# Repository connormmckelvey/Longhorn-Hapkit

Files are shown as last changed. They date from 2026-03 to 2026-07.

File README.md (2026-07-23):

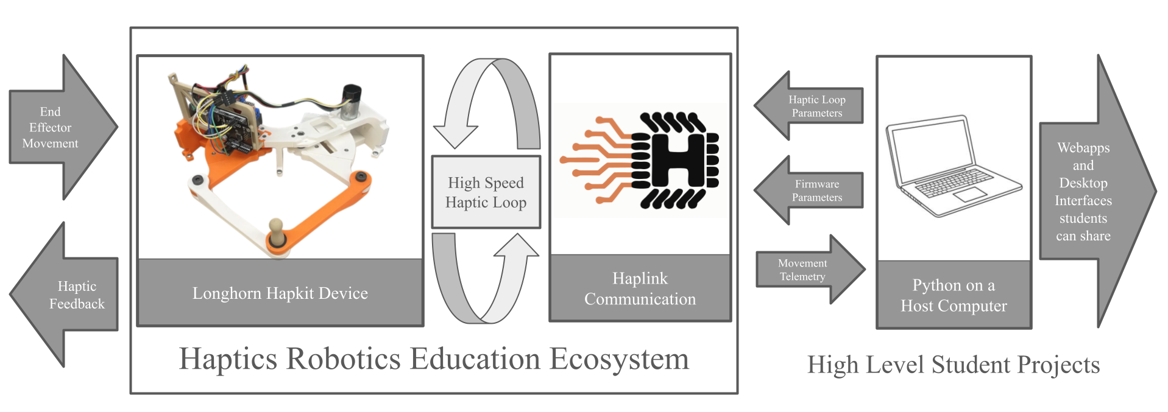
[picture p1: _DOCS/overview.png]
Overview


# The Longhorn Hapkit
### A Complete Haptic Robotics Education Ecosystem
---
###### Written by Ross Neuman and Connor McKelvey for the Human Enabled Robotics Lab at UT Austin under Professor Ann Fey.

> **A note to the reader:** The Longhorn Hapkit aims to provide a complete toolset to enable anyone to learn robotics through the interdisplinary and universal sense of touch. These low-cost devices enable students to learn mechanical design, electronics, and software engineering. Hopefully the provided documents supply an ample jumping off point for educators and ambitious students alike to look deeper into the field of robotics and create their very own projects and improvements to our ecosystem.

#### This Project Includes:
- 1 Degree of Freedom Haptic device design
    - A simple first device to build and learn what haptics is, use this to render your first artifical wall, dampener, or spring!
- 2 Degree of Freedom Haptic device design
    - Once you've mastered the 1-DOF enviroments, combine two of them into our 2-DOF design opening a world a possibilies. From teleoperation to pong games, use this device to make games or more complex simulations!
- Haplink implementation for device interfacing with Python

#### Repository Structure
```
DOCS/
    * supplemental material, diagrams, bill of materials
firmware/
    * files are numbered coresponding to /python scripts
    1DOF/
    2DOF/
    includes/ 
        * header files used by various scripts
python/
    1DOF/
    2DOF/
    tools/ 
        *helper scripts (e.g. to find connect ports)
README.md
platformio.ini *configuration file showing dependencies
```
#### Environment Setup
<table>
<!--
  <tr>
    <th colspan="2" align="center">Environment Setup</th>
  </tr>
-->
  <tr>
    <td width="50%"><b>Arduino IDE Setup</b></td>
    <td width="50%"><b>PlatformIO Setup</b></td>
  </tr>
  <tr>
    <td valign="top">
      1. Download and install the <b>Arduino IDE</b>.<br><br>
      2. Open the <b>Library Manager</b> from the left sidebar.<br><br>
      3. Search for <b>Haplink</b> by Connor McKelvey.<br><br>
      4. Select version <b>1.0.3</b> and click <b>Install</b>.<br><br>
      5. Select <b>Arduino Uno</b> as your board.<br><br>
      5. Copy the contents of <code>1_basic.cpp</code> into the main window and hit compile.<br><br>
      6. Write code!<br><br>
      Note: you will need to use another IDE to run future python scripts 
    </td>
    <td valign="top">
      1. Download and install <b>VS Code</b> with the <b>PlatformIO Extension</b>.<br><br>
      2. Open the <b>PlatformIO Home</b> and create a new project.<br><br>      
      3. Open the <b>PlatformIO Home</b> and click on <b>Libraries</b>.<br><br>
      4. Search for <b>Haplink</b> by Connor McKelvey.<br><br>
      5. Copy <code>1_basic.cpp</code> into the <code>src/</code> folder of the project<br><br>
      6. Run <code>PlatformIO:Upload</code> and watch the magic happen.<br><br>
      7. When you are ready to interface with Python, navigate to <a href="https://github.com/connormmckelvey/Haplink">github.com/connormmckelvey/Haplink</a> and follow the instructions for PlatformIO install.
    </td>
  </tr>
</table>

<div style="display: flex; justify-content: center;">
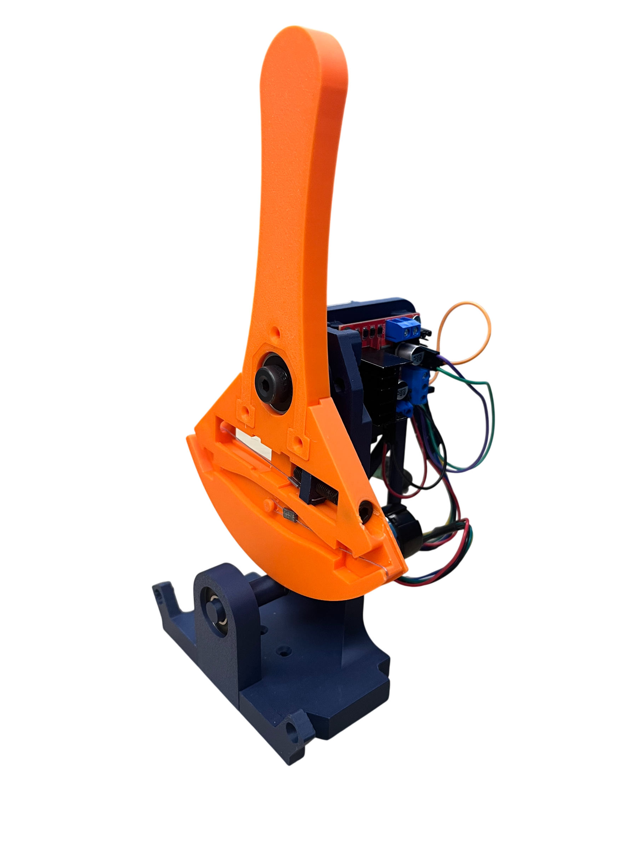
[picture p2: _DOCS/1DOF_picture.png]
1DOF
  
</div>

#### 1-DOF Longhorn Hapkit
The 1 Degree of Freedom design implements a single capstan drive to control the end-effector position. 

<div style="display: flex; justify-content: center;">
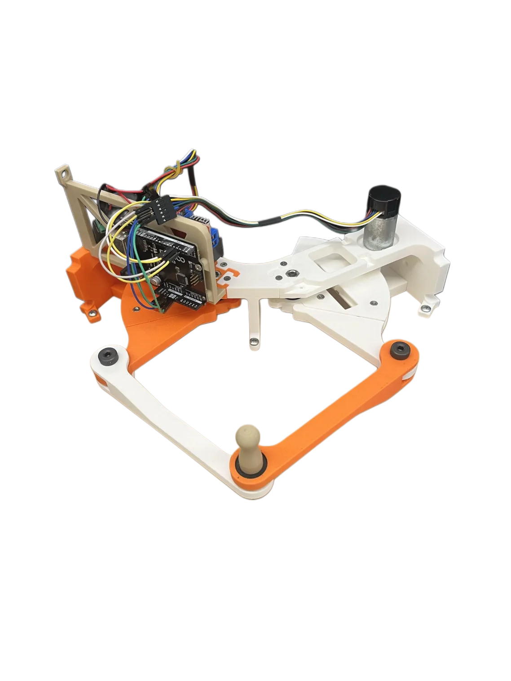
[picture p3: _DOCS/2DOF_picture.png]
2DOF
  
</div>

#### 2-DOF Longhorn Hapkit Expansion
blah blah

<div style="display: flex; justify-content: center;">
  HAPLINK
</div>

#### Python Interfacing with Haplink
blah blah

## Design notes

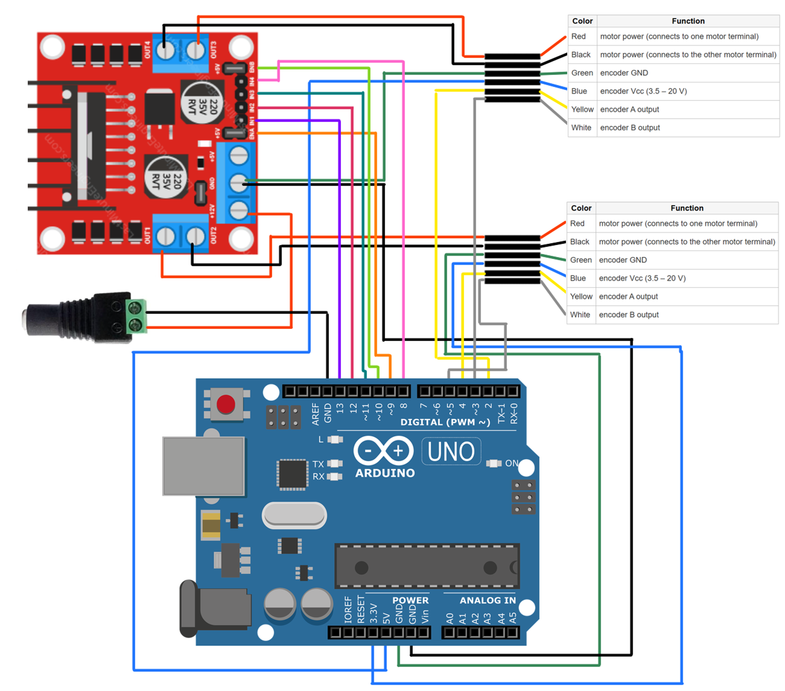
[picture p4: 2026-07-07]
_DOCS/2DOF_wire_diagram.png

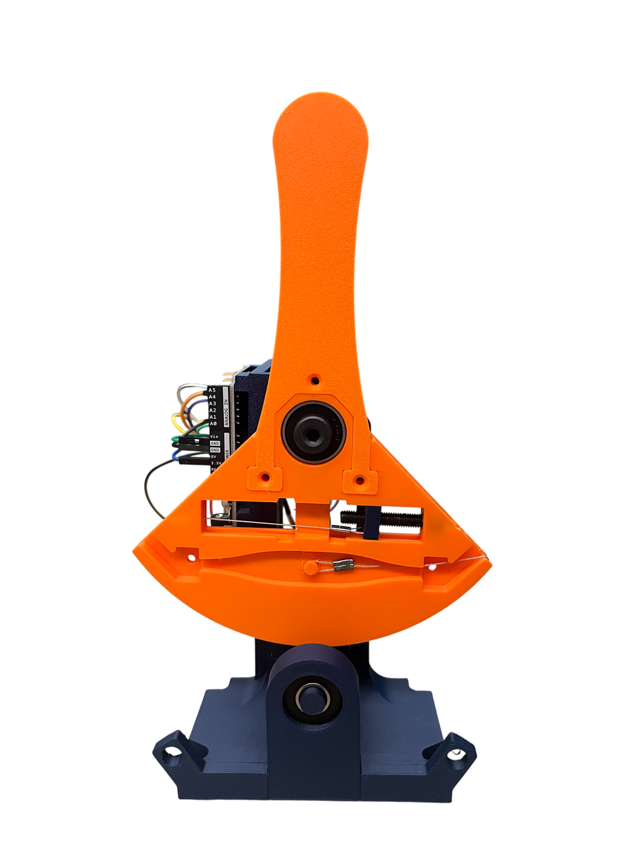
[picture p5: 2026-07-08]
_DOCS/1DOF_picture_front.png

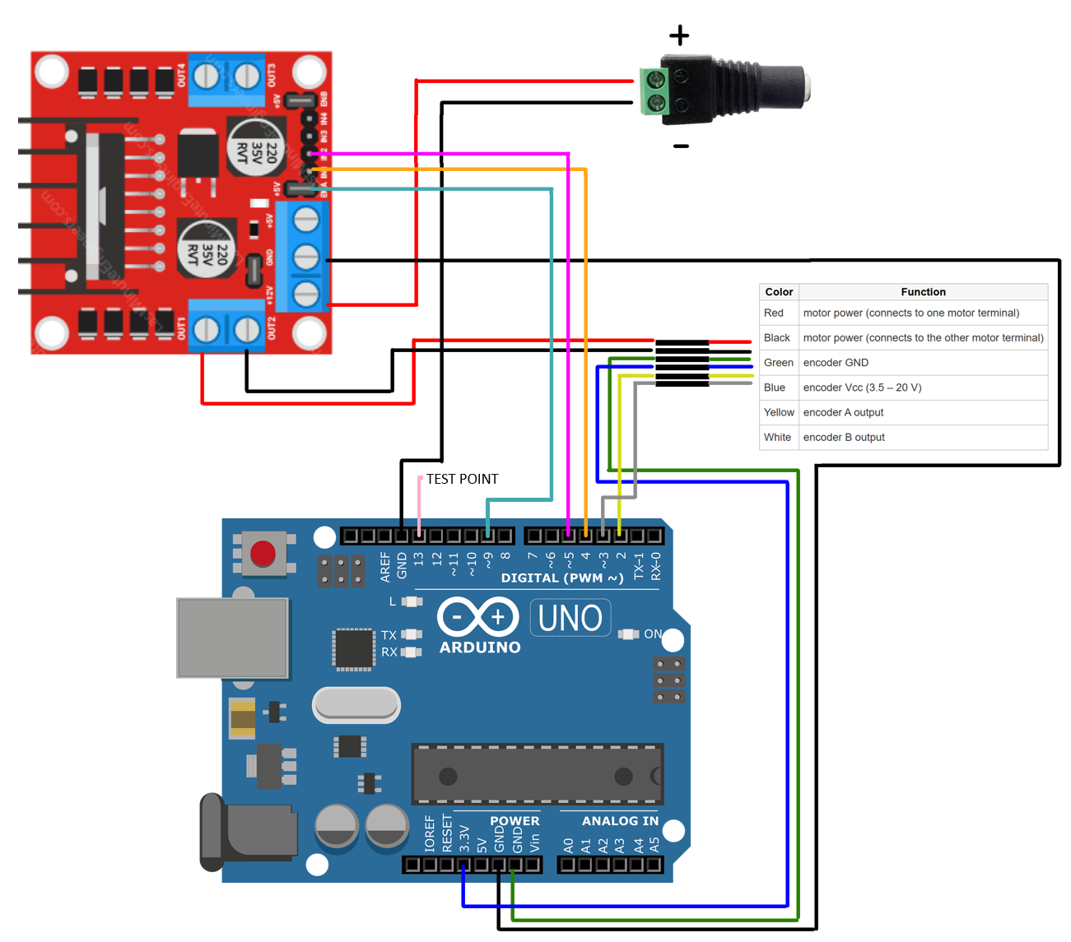
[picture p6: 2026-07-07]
_DOCS/1DOF_wire_diagram.png

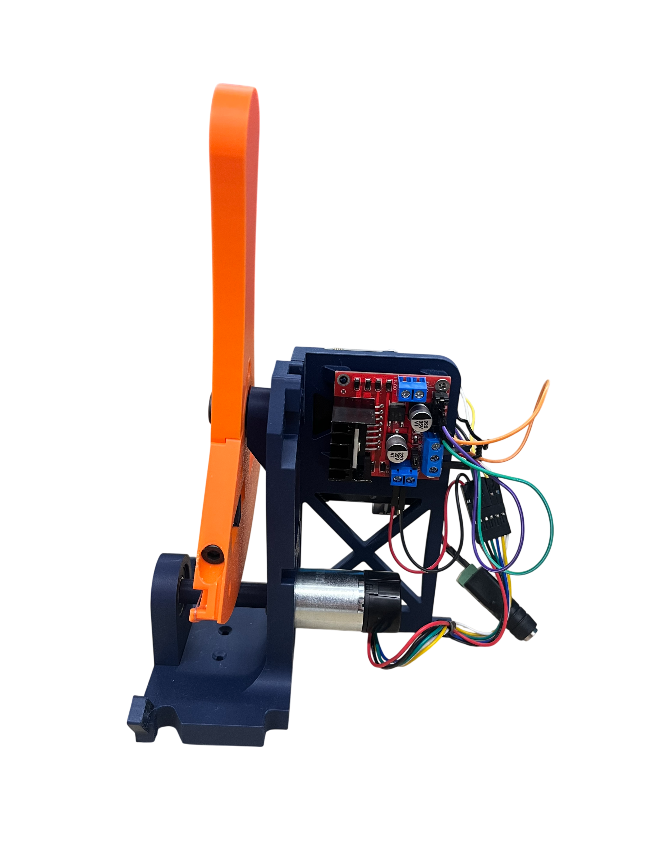
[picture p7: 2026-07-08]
_DOCS/1DOF_picture_side.png

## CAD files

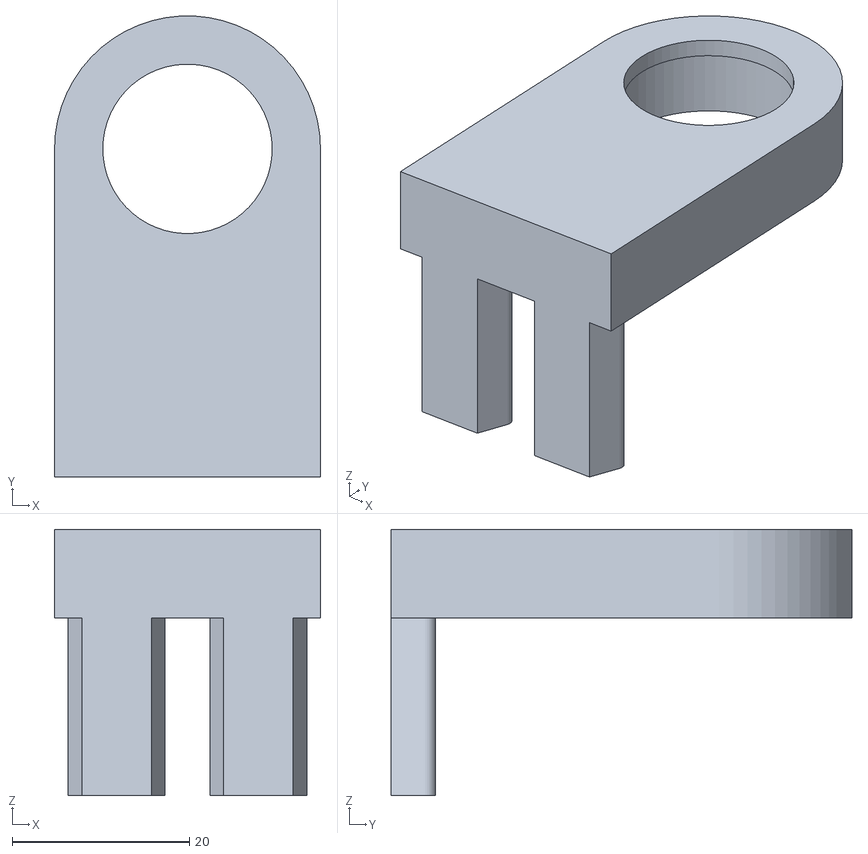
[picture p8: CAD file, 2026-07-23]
cad/1DOF/bearing_housing.stl
30.0 x 52.0 x 30.0

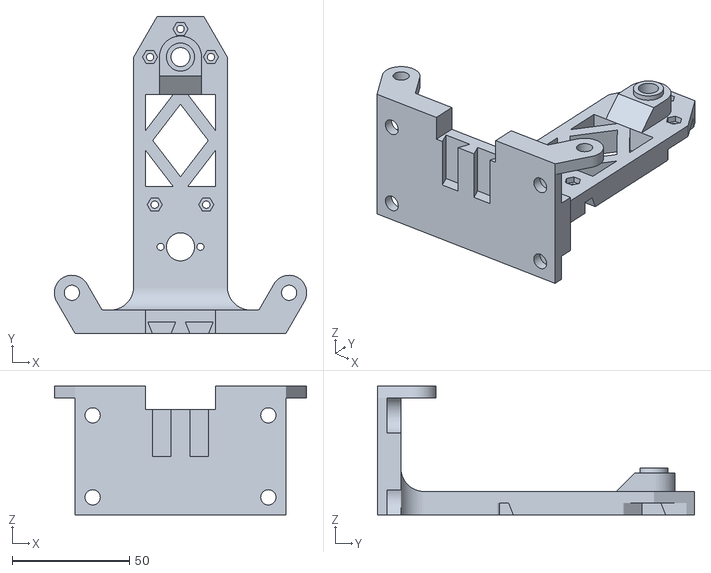
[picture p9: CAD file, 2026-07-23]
cad/1DOF/base.stl
107.7 x 135.3 x 55.0

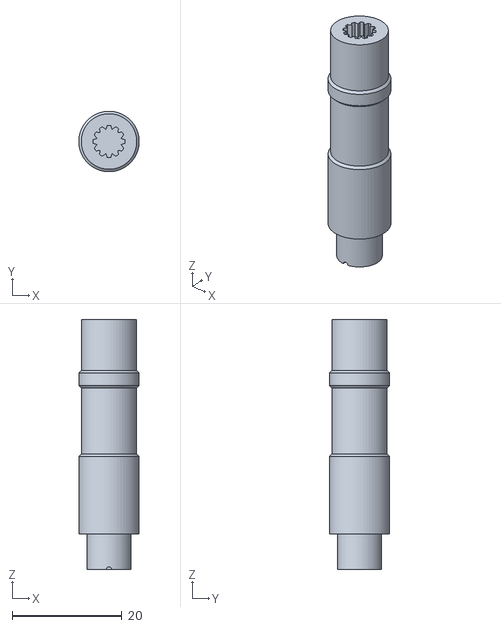
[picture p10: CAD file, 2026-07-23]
cad/1DOF/motor_shaft.stl
11.0 x 11.0 x 45.5

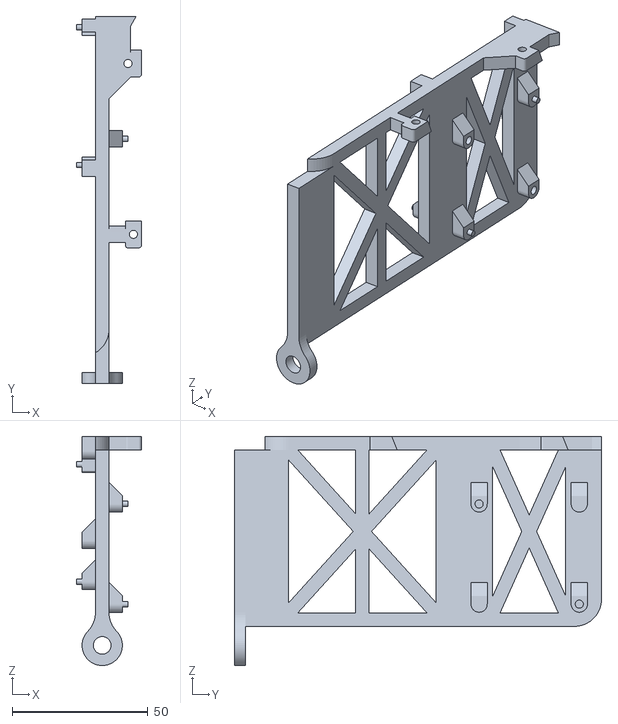
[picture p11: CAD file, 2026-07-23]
cad/1DOF/pcb_mount.stl
24.0 x 135.3 x 84.4

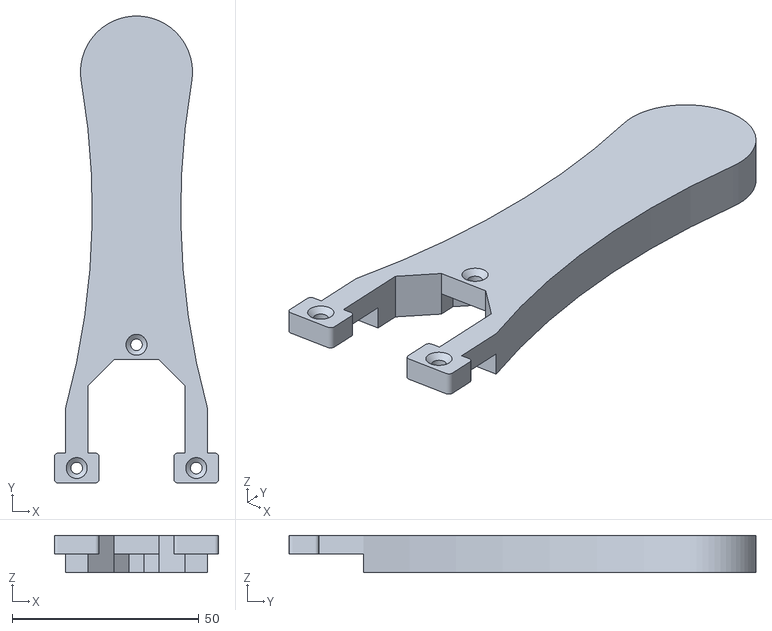
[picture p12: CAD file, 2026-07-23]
cad/1DOF/handle.stl
44.0 x 125.0 x 10.0

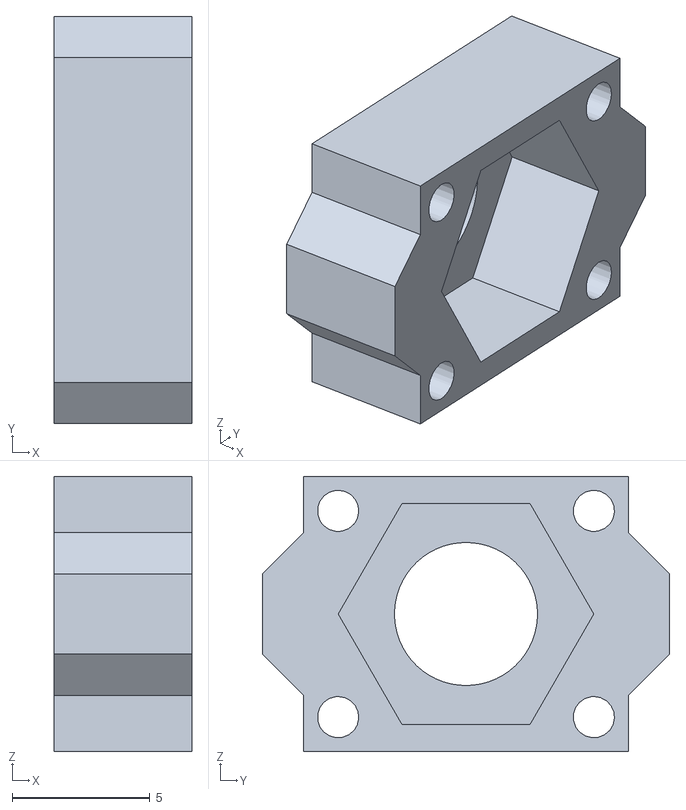
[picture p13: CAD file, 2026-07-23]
cad/1DOF/tensioner.stl
5.00 x 14.8 x 10.0

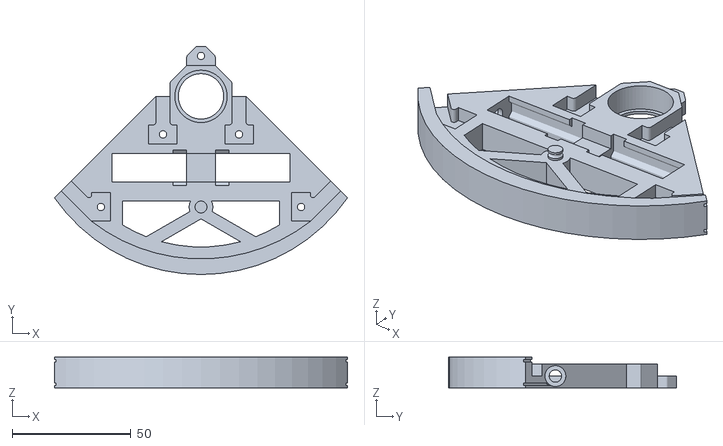
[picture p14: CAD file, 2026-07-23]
cad/1DOF/sector_pulley.stl
123.4 x 96.0 x 13.0

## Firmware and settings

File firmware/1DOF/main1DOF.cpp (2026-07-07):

//IF YOU USE THIS CODE, MAKE SURE THE PWMout WIRE IS MOVED TO PIN 9
//Write all serial messages in loop(), do not do serial communication in ISR

//Hapkit basic environments code + CAR STEERING GAME mode
//Base: Ann Majewicz Fey and Ross Neuman 2/13/26
//Car game mode added for steering-game camp project

#include <Encoder.h>
#include <Haplink.h>
#include <math.h>
#define ENCODER_OPTIMIZE_INTERRUPTS

// Pin Declarations
const int MotIn1 = 4;   //motor login pin 1
const int MotIn2 = 5;   //motor logic pin 2
const int PWMout = 9;   //PWM signal to control voltage to motor (pins 9 and 10 are on timer1 (16bit))

const int encPinA = 3;  //encoder output "A"
const int encPinB = 12;  //encoder output "B"

Encoder encoder(encPinB, encPinA);  //the encoder library uses the pulses from the two encoder outputs to get one 48 CPR angular positon
Haplink haplink;

float encoderResolution = 48;  //encoder has 48 counts per revolution (CPR)
float pos = 0; //encoder position in ticks (initialized at zero)


// Change handle_length to reflect the handle you printed!
float handle_length = 0.085;  // length of your handle[m]
float pulley_radius = 0.005;  // radius of motor pulley[m]
float sector_radius = 0.075;  // radius of sector[m]

// Kinematics variables
float handle_pos = 0;      // position of the handle [we will calculate it in cm in code below]
float handle_pos_prev = 0; // previous handle position

float pulley_angle;     // motor pulley angle (radians)
float sector_angle;          // sector angle (radians)

// velocity using 1st-order low-pass filter
float handle_vel = 0;         // handle velocity
float handle_vel_prev = 0;    // previous velocity

float dt = 0.001;  // time steps of 1ms (1kHz control loop)

// define "r" based on cutoff frequency
float cutoff_frequency = 40;                //cutoff frequency [Hz]
float r = exp(-2*M_PI*cutoff_frequency*dt); //filter constant

float duty; //duty cycle for PWM (-400 to 400)

// enumerate the different possible haptic modes
enum hModes{
  ZERO,
  SPRING,
  DAMPER,
  SPRING_DAMPER,
  WALL,
  BUMP_VALLEY,
  TEXTURE,
  CAR_GAME
};

// pick which mode is there from the start
hModes hapticMode = SPRING;
//volatile lets the compiler know this value may change due to outside factors (e.g. keyboard press or PC command)

// ---- Car game variables ----
float road_pull = 0;       // signed force nudging the handle toward the curve's "correct" angle
int16_t surface_state = 0; // 0 = normal road, 1 = rumble strip, 2 = off-road, 3 = crash
float game_speed = 0;      // normalized 0 (stopped) to 1 (max speed)

// internal state for the car game (not sent over Haplink, just used locally)
int16_t prev_surface_state = 0;
int crash_timer = 0;          // counts down (in ms) while a crash jolt is playing
unsigned long isr_ms = 0;     // free-running millisecond counter, incremented in the ISR


// Edit this function if you want to add variables that can be sent or recived from any provided python script via Haplink
// Parameters are values sent to the Hapkit, Telemetry are values sent from the Hapkit
// "type" mentioned below can be any of the following: HL_UINT8, HL_INT16, HL_INT32, HL_FLOAT, HL_DOUBLE
// simply add a line using register_____(a new ID value, &<variable>, type)
void registerHaplinkVariables(){
  haplink.registerParam(0, &hapticMode, HL_INT16);

  // car game params (sent from the PC each frame)
  haplink.registerParam(1, &road_pull, HL_FLOAT);
  haplink.registerParam(2, &surface_state, HL_INT16);
  haplink.registerParam(3, &game_speed, HL_FLOAT);

  haplink.registerTelemetry(0, &handle_pos, HL_FLOAT);
  haplink.registerTelemetry(1, &handle_vel, HL_FLOAT);
}


void setup() {

  //****DO NOT CHANGE*****
  //set up PWM on Timer1 so it's faster and we don't hear the annoying hum anymore
  //this stuff is more in the weeds, please consult the ATmega328/P datasheet for more detailed info (p. ~170)
  //set phase and frequency correct pwm at 20kHz:
  TCCR1A = (1 << COM1A1); //clear OC1 on compare match when up-counting, sets on match when down-counting
  TCCR1B = (1 << WGM13) | (1 << CS10); //waveform generation mode 8 (phase/freq correct, ICR1 top), prescaler = 1
  ICR1 = 400; //ICR1 defines TOP in WGM8
  // the results of the above code is:
  // freq_PWM = freq_CPU / (2 * prescaler * TOP)
  // freq_PWM = 16,000,000 / (2 * 1 * 400) = 20,000 or 20 kHz

  // Set motor controlling pins to OUTPUT mode
  pinMode(13, OUTPUT); //pin 13 is the onboard LED, we will use it to indicate when we are sending telemetry
  pinMode(MotIn1, OUTPUT);
  pinMode(MotIn2, OUTPUT);
  pinMode(PWMout, OUTPUT);

  // Initalize motor direction and set to 0 (no spin)
  digitalWrite(MotIn1, HIGH);
  digitalWrite(MotIn2, LOW);
  OCR1A = 0;  //write to this register for PWM later instead of "analogwrite"

  // Configure control interrupt with Timer2 to make 1kHz control loop
  cli();  //disable interrupts

  TCCR2A = 0;
  TCCR2B = 0;

  // waveform generation mode 2 -- clear timer on compare match (CTC) mode
  TCCR2A |= (1 << WGM21);

  // Prescaler = 64
  TCCR2B |= (1 << CS22);

  OCR2A = 249;
  // freq = freq_cpu / (prescaler * (1 + OCR2A))
  // freq = 16,000,000 / (64 * (1 + 249)) = 1000 Hz or 1 kHz
  // no multiplication by factor of 2 in denominator as Timer2 is single-slope (Timer1 is dual-slope)

  // enable interrupt
  TIMSK2 |= (1 << OCIE2A);

  sei();   // enable interrupts

  Serial.begin(115200);  //begin serial communication
  haplink.begin(Serial);
  registerHaplinkVariables();
}

void setMotor(int motCommand) {
  //motCommand range: -400 to 400
  //Limit values to this range
  if (motCommand > 400) {
    motCommand = 400;
  }
  if (motCommand < -400) {
    motCommand = -400;
  }

  //command motor speed and direction based on motCommand
  if(motCommand > 0) {
    digitalWrite(MotIn1, LOW);
    digitalWrite(MotIn2, HIGH);
    OCR1A = motCommand;
  }
  if(motCommand < 0) {
    digitalWrite(MotIn1, HIGH);
    digitalWrite(MotIn2, LOW);
    OCR1A = -motCommand;
  }
}
// write each haptic environment as a function that returns the desired duty cycle for PWM
// writing as functions can help make the code easier to parse (plus you can collapse them in the IDE)

// simple spring
float spring(float x){
  float k = 60;
  return -k * x;
}

// simple damper
float damper(float v){
  float b = 8;
  return -b * v;
}

// spring plus damping
float springDamper(float x, float v){
  float k = 80;
  float b = 7;
  return -k * x - b * v;
}

// wall with damping
float wall(float x, float v) {
  float x_wall = 2;   // wall location (cm)
  float k_wall = 200; // wall stiffness
  float b_wall = 8;  // wall damping (try increasing this to feel some instability vibrations)
  if (x > x_wall)
  {
    return -k_wall * (x - x_wall)  + -b_wall*(v);
  }
  else
  {
    return 0;
  }
}

// Bump and Valley
float bumpValley(float x){
  float bump_location = 2;
  float bump_length = 3;
  float bump_height = 2;
  float bump_k = 200;
  float valley_location = -2;
  float valley_length = 3;
  float valley_height = 2;
  float valley_k = 200;

  if ((x <= (bump_location + bump_length / 2)) && (x >= (bump_location - bump_length / 2))) {
    // The handle is on the bump
    return bump_k * bump_height * cos(M_PI / bump_length * (x - bump_location)) * sin(M_PI / bump_length * (x - bump_location));
  } else if ((x <= (valley_location + valley_length / 2)) && (x >= (valley_location - valley_length / 2))) {
    // The handle is in the valley
    return -valley_k * valley_height * cos(M_PI / valley_length * (x - valley_location)) * sin(M_PI / valley_length * (x - valley_location));
  } else {
    // the handle is on flat ground
    return 0;
  }

}

//Texture with sinusoid
float texture(float x, float v){
  float w = 0.5; //width of damping area (cm)
  float b = 7;  //damping constant
  if (sin((M_PI * x) / w)> 0) {
    return -b * v;
  }
  else{
    return 0;
  }
}

// ---- CAR STEERING GAME ----
// x = handle position (cm), v = handle velocity (cm/s)
//   1) a self-centering spring, stiffer at higher game_speed
//   2) road_pull: a tug toward the "correct" wheel angle for the upcoming curve
//   3) surface effects: rumble strip buzz, off-road drag, or a crash jolt
float carGame(float x, float v){
  float k_center = 90.0;            // Increased from 55 for much heavier steering feel
  float b_base = 6.0;               // Base damping
  float b_center_extra = 10.0;      // Extra damping near center (middle of the steer)
  float pull_gain = 18.0;           // scales road_pull (from PC) into an actual force (increased slightly)
  float speed_stiffness_gain = 45.0; // extra stiffness added at higher speed (increased from 35)

  // ---- crash jolt (overrides everything else while it plays) ----
  // detect a NEW crash (rising edge) so we only trigger once per crash event
  if (surface_state == 3 && prev_surface_state != 3) {
    crash_timer = 200; // length of jolt, in ms
  }
  prev_surface_state = surface_state;

  if (crash_timer > 0) {
    // strong, decaying, alternating jolt
    float decay = crash_timer / 200.0;
    float f = 300.0 * decay;
    if ((crash_timer % 20) >= 10) f = -f; // alternate direction for a "rattle" feel
    crash_timer--;
    return f;
  }

  // ---- base self-centering spring ----
  float force = -(k_center + speed_stiffness_gain * game_speed) * x;
  
  // Damping is dynamically boosted close to the middle of the steer
  float b_dynamic = b_base + (b_center_extra / (1.0 + abs(x)));
  force += -b_dynamic * v;

  // ---- road pull toward the curve's correct angle ----
  force += pull_gain * road_pull;

  // ---- surface effects ----
  if (surface_state == 1) {
    // rumble strip: fast buzz, ~40 Hz
    force += 60.0 * sin(2 * M_PI * 40.0 * (isr_ms * dt));
  } else if (surface_state == 2) {
    // off-road: heavy, sluggish wheel
    force += -12.0 * v;
  }

  return force;
}

// The "superloop" below can now just be used for things like serial communication
// runs in 2ms (all of that time is spent in sending telemetry over serial)
// haplink.update() runs in us even if receiving a packet
// haplink.sendAllTelemetry() runs about 1ms per telemetry variable (14 bytes)
void loop() {
  // Update param variables by reading incoming serial packets from PC
  //digitalWrite(13, HIGH); //turn on LED to indicate we are sending telemetry
  haplink.update();
  //digitalWrite(13, LOW); //turn off LED to indicate we are done sending telemetry

  // allow serial monitor to read for a new mode and switch accordingly
  if(Serial.available()){
    char s = Serial.read();
    if (s == '0') hapticMode = ZERO;
    if (s == '1') hapticMode = SPRING;
    if (s == '2') hapticMode = DAMPER;
    if (s == '3') hapticMode = SPRING_DAMPER;
    if (s == '4') hapticMode = WALL;
    if (s == '5') hapticMode = BUMP_VALLEY;
    if (s == '6') hapticMode = TEXTURE;
    if (s == '7') hapticMode = CAR_GAME;
  }

  haplink.sendAllTelemetry();
  //digitalWrite(13, LOW); //turn off LED to indicate we are done sending telemetry
}

//Haptic loop running at 1kHz using an interrupt service routine (ISR) for reliable calling
//runs in ~100us
ISR(TIMER2_COMPA_vect) {
  //digitalWrite(13, HIGH); //turn on LED to indicate we are sending telemetry
  isr_ms++; // free-running ms counter, used for buzz timing in carGame()

  // read encoder
  pos = encoder.read();

  pulley_angle = (pos / encoderResolution) * 2 * M_PI; //angular position of motor pulley in radians

  sector_angle = (pulley_angle * pulley_radius) / sector_radius; //angular position of sector pulley in radians

  //determine handle position in cm
  handle_pos = 100*(handle_length * pulley_radius * pulley_angle) / sector_radius;

  // handle velocity (cm/s) using a 1st-order low pass filter with constant r defined in setup()
  handle_vel = r * handle_vel_prev + (1 - r) * (handle_pos - handle_pos_prev) / dt;

  // update "previous" terms for next loop
  handle_pos_prev = handle_pos;
  handle_vel_prev = handle_vel;

  // switch statement to determine which haptic mode we will use
  switch(hapticMode){
    case ZERO:
      duty = 0;
      encoder.write(0);
      pos = 0;
      break;
    case SPRING:
      duty = spring(handle_pos);
      break;
    case DAMPER:
      duty = damper(handle_vel);
      break;
    case SPRING_DAMPER:
      duty = springDamper(handle_pos, handle_vel);
      break;
    case WALL:
      duty = wall(handle_pos, handle_vel);
      break;
    case BUMP_VALLEY:
      duty = bumpValley(handle_pos);
      break;
    case TEXTURE:
      duty = texture(handle_pos,handle_vel);
      break;
    case CAR_GAME:
      duty = carGame(handle_pos, handle_vel);
      break;
  }

  // command motor based on duty cycle (-400 to 400)
  setMotor(duty);
  //digitalWrite(13, LOW); //turn off LED to indicate we are done sending telemetry
}

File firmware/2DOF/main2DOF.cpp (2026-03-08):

//Hapkit 2-DOF
//Ross Neuman 2026
//Kinematics as defined in Campion, et al. 2006

#define ENCODER_OPTIMIZE_INTERRUPTS

#include <Encoder.h>
#include "haplink.h"
#include "haptic_objects_2d.h"

// Haplink uses Serial for a binary protocol.
// Raw Serial.print() debugging can corrupt Haplink packets.
#ifndef ENABLE_DEBUG_SERIAL
#define ENABLE_DEBUG_SERIAL 0
#endif

enum hModes{
  ZERO,
  JOYSTICK,
  GRID,
  CIRCLES,
  HARP,
  DAMP,
  WALL,
  JOYSTICK_DAMPED,
  BOX_OBSTACLE
};

volatile hModes hapticMode = BOX_OBSTACLE;

// Single editable rectangle for BOX_OBSTACLE mode.
// Units match nX/nY in this firmware.
rect_t box_rect = { {0.01f, -0.05f}, 0.05f, 0.05f };

//Motor/encoder 1 pins
const int pwm1 = 9;
const int mot1A = 13;
const int mot1B = 12;
const int enc1A = 4;
const int enc1B = 5;

//Motor/encoder 2 pins
const int pwm2 = 10;
const int mot2A = 11;
const int mot2B = 8;
const int enc2A = 2;
const int enc2B = 3;

Haplink haplink;

//Set up encoders
Encoder enc1(enc1A,enc1B);
long pos1 = 0;
long lastPos1 = 0;

Encoder enc2(enc2A,enc2B);
long pos2 = 0;
long lastPos2 = 0;

//Convert encoder readings to angular displacement of arms
float countsPerRad = 114.5915; //encoder counts per radian at the arm (48cpr*15gearing*2pi^-1)

//angular displacement of arms
float t1, t5;

//End effector X and Y location (define 0,0 at motor 1 shaft per Campion et al 2005)
float X, Y;

//End effector location normalized to workspace (0,0)
float nX, nY, lastnX, lastnY, vX, vY, lastVx, lastVy;

// Minimal telemetry to keep Haplink PC-side clients happy.
// The Python client considers the device connected only after it receives
// at least one valid Haplink packet.
float hl_tel_nx = 0.0f;
float hl_tel_ny = 0.0f;

//1ms loops -- NOTE: this is not currently true :(
float dt = .003;

// define filter "r" based on cutoff frequency
float fc = 30;                //cutoff frequency [Hz]
float r = exp(-2*M_PI*fc*dt); //filter constant

//Arm lengths
float a1 = 0.1;
float a2 = 0.128;
float a3 = 0.128;
float a4 = 0.1;
float a5 = 0.06;

//Terms used in forward kinematics calculation
float p2x, p2y, p4x, p4y, p2p4, p2ph, p3ph, phx, phy;

//Terms used in Jacobian calculation
float d, b, h, d1x2, d1y2, d5x4, d5y4, d1d, d1b, d1h, d5d, d5b, d5h, d1yh, d5yh, d1xh, d5xh, d1y3, d5y3, d1x3, d5x3;
float d1x4 = 0;
float d1y4 = 0;
float d5x2 = 0;
float d5y2 = 0;

//forces to render in the workspace (N)
float Ftot, Fx, Fy;

//Direction of force application
float dir;

//Torques to command of the motors
float tau1, tau2;

//output of dist() function
float distance;

//PWM control of motors
float duty1, duty2;
int out1, out2;

//Spring constant of joystick mode
float k_joy;

//Intensity of bumps and grid resolution in grid mode
float k_bump, bump_threshold;
float grid_res = 5;

float b_damping;

float k_wall;
float b_wall;

//Pi used for calculating periodic stuff
float pi = 3.14159;

//Forward declarations (allow calling functions before their definitions)
void FK(float theta1, float theta5);
void Jac();
void Torque();
void Velocity();
float dist(float x1, float y1, float x2, float y2);

void setup() {
  Serial.begin(115200);
  haplink.begin(Serial);
  haplink.registerParam(0, (void*)&hapticMode, HL_DataType::HL_UINT8);

  // Telemetry ids:
  //   0: normalized X
  //   1: normalized Y
  haplink.registerTelemetry(0, (void*)&hl_tel_nx, HL_DataType::HL_FLOAT);
  haplink.registerTelemetry(1, (void*)&hl_tel_ny, HL_DataType::HL_FLOAT);

  // Expose the box rectangle over Haplink so Python can move/resize it.
  // Param ids:
  //   10: bottom_left.x
  //   11: bottom_left.y
  //   12: width
  //   13: height
  haplink.registerParam(10, (void*)&box_rect.bottom_left.x, HL_DataType::HL_FLOAT);
  haplink.registerParam(11, (void*)&box_rect.bottom_left.y, HL_DataType::HL_FLOAT);
  haplink.registerParam(12, (void*)&box_rect.width, HL_DataType::HL_FLOAT);
  haplink.registerParam(13, (void*)&box_rect.height, HL_DataType::HL_FLOAT);

  TCCR1A = (1 << COM1A1) | (1 << COM1B1); //clears OC1 on compare match when up-counting, sets on match when down-counting
  TCCR1B = (1 << WGM13) | (1 << CS10); //waveform generation mode 8 (phase/freq correct, ICR1 top), prescaler = 1
  ICR1 = 400; //ICR1 defines TOP in WGM8
  
  //Set all the motor control pins to outputs
  pinMode(pwm1, OUTPUT);
  pinMode(pwm2, OUTPUT);
  pinMode(mot2A, OUTPUT);
  pinMode(mot2B, OUTPUT);
  pinMode(mot1A, OUTPUT);
  pinMode(mot1B, OUTPUT);
  
  //Initialize motor directions and set speeds to 0
  digitalWrite(mot1A, HIGH);
  digitalWrite(mot1B, LOW);
  //analogWrite(pwm1,0);
  
  digitalWrite(mot2A, HIGH);
  digitalWrite(mot2B, LOW);
  //analogWrite(pwm2,0);

  //Initialize positions (should place end effector at center of workspace before powering up device)
  lastPos1 = 0;
  lastPos2 = 0;
  lastnX = 0;
  lastnY = 0; 
}
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
